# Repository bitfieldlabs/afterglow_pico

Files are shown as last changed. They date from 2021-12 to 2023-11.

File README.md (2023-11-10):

# Afterglow Pico
The afterglow pico is the newest and tiniest addition to the afterglow family.

It operates differently from the other boards as it is hooked directly into the WPC bus. The underlying concept remains the same though. The original lamp matrix is resampled at 4kHz and PWM is used to add a nice afterglow to the LEDs in your pinball machine.

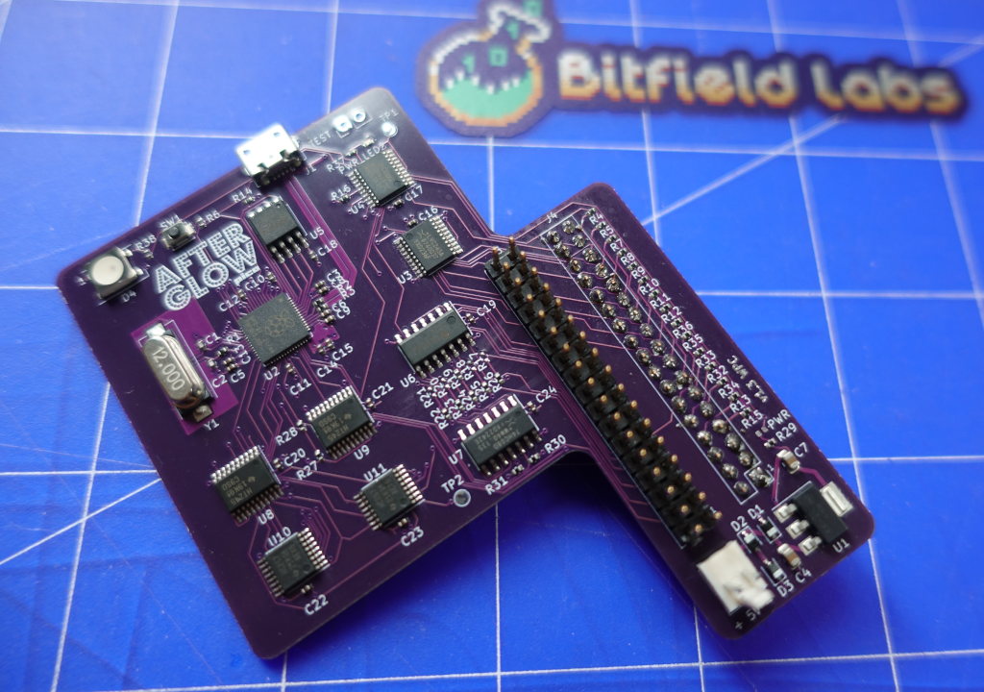
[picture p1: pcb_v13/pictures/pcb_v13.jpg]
afterglow_pico Afterglow Pico


## Disclaimer

| :boom: WARNING  :boom:            |
|:---------------------------|
| **Messing with your pinball machine's data bus is risky!** |
| *The AG pico is an experiment, for stable afterglow please<br>use the standard afterglow boards.* |

Afterglow is distributed in the hope that it will be useful but WITHOUT ANY WARRANTY; without even the implied warranty of
MERCHANTABILITY or FITNESS FOR A PARTICULAR PURPOSE.  See the GNU Lesser General Public License for more details.

## Concept
The concept is quite simple:
* The lamp matrix status is sampled directly from the WPC bus by the Raspberry Pi Pico
* All non lamp related address lines (solenoids etc.) are logically combined (AND) to monitor bus activity
* All non lamp related bus events are directly routed through a multiplexer to the output. Only the lamp events are filtered out. This ensures that original bus events always take precedence over the Pi signals and that no original events are lost.
* The Pi Pico interleaves the upsampled 4kHz PWM lamp matrix events into the bus through the multiplexer

Afterglow Pico Schematic

## Compiling the Raspberry Pi Pico code

The [pi_pico_code folder](https://github.com/bitfieldlabs/afterglow_pico/tree/master/pi_pico_code) contains a [platformio](https://platformio.org/) project which can be compiled using [Visual Studio Code](https://code.visualstudio.com/). It requires the [wizio-pico](https://github.com/Wiz-IO/wizio-pico) platform extension.

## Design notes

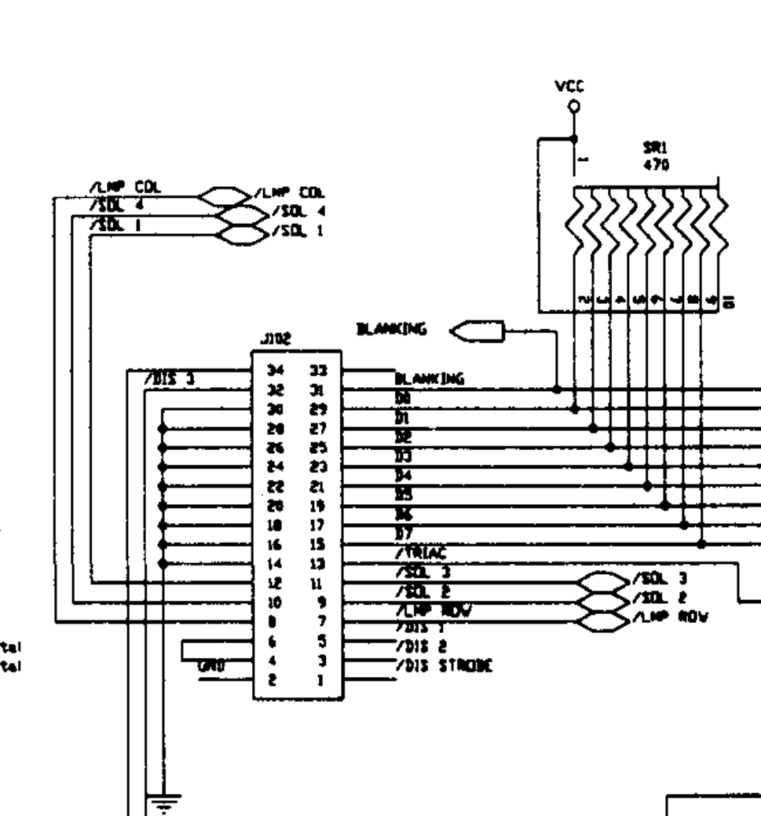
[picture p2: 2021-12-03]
docs/wpc95_bus.png

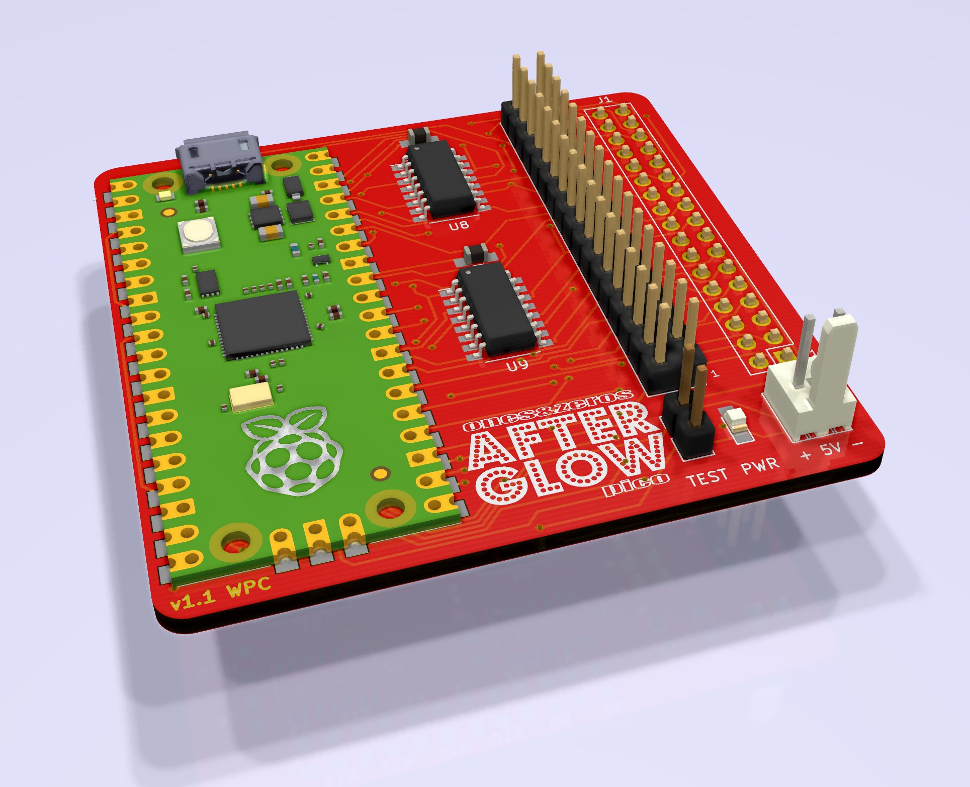
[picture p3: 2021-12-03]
docs/pcb_v11_render.jpg

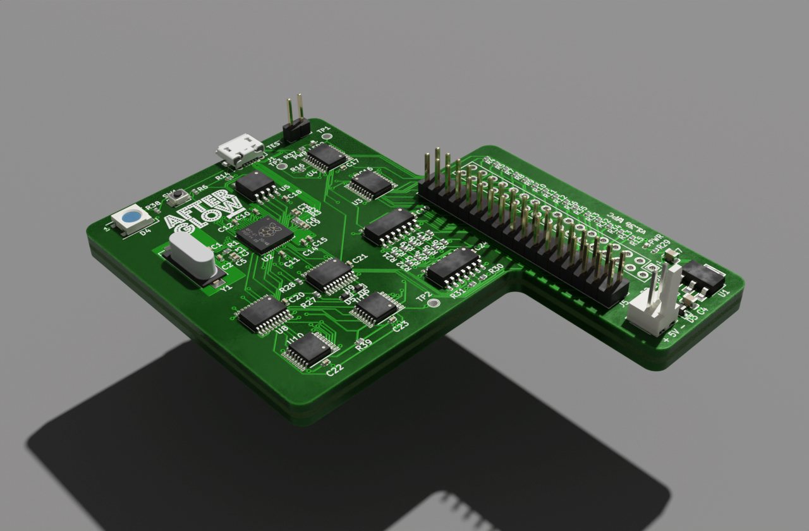
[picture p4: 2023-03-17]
pcb_v13/render/pcb_v13_b.jpg

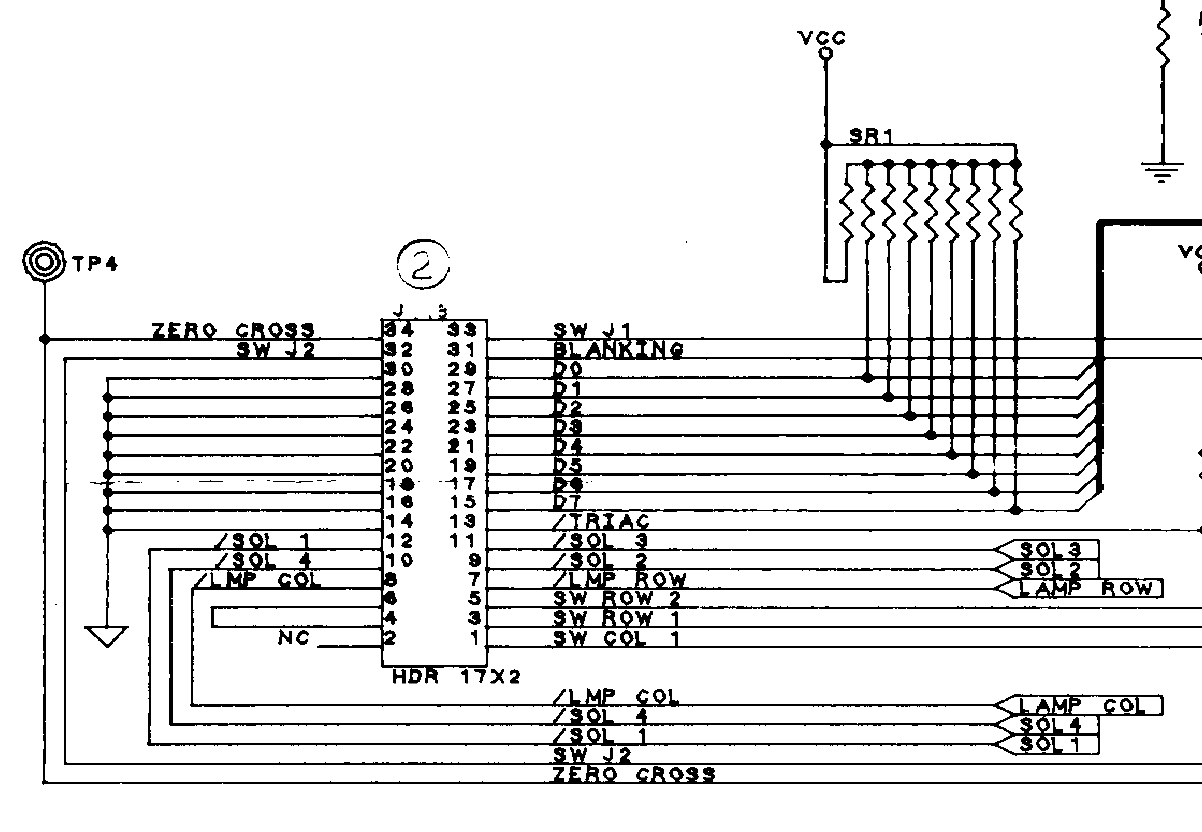
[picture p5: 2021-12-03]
docs/wpc_bus.png

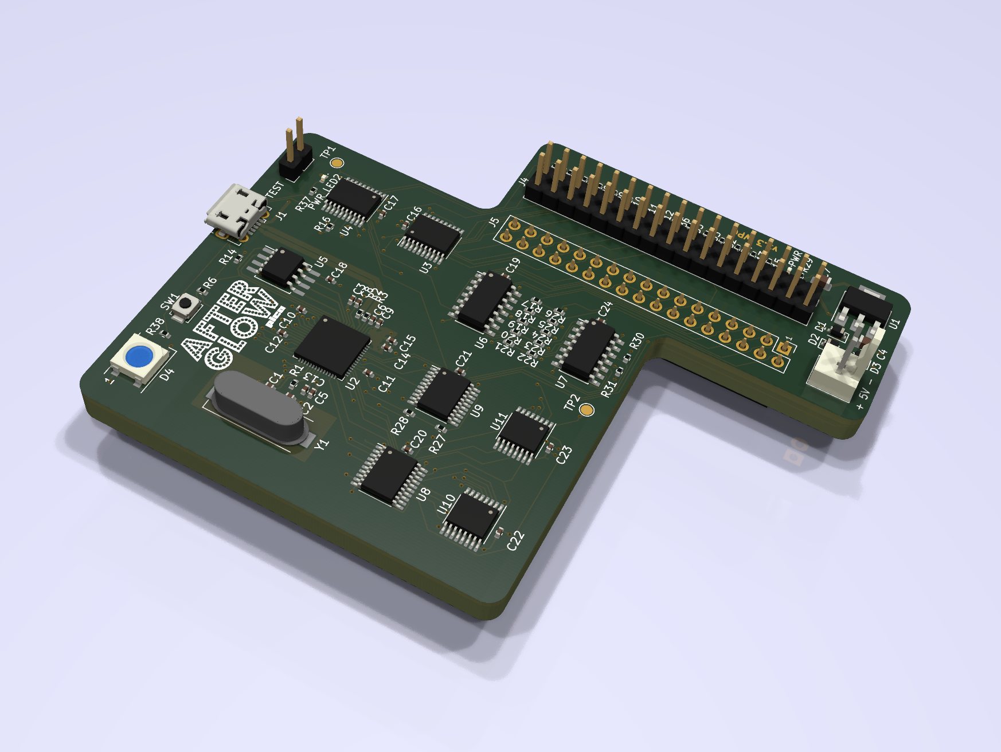
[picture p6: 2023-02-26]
pcb_v13/render/pcb_v13.jpg

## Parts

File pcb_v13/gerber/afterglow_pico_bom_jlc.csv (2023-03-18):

Comment | Designator | Footprint | LCSC Part #
27p | C1,C2 | C_0402_1005Metric | C107002
100n | C3,C5,C8,C10,C11,C12,C13,C14,C15,C18 | C_0402_1005Metric | C131394
10u | C4,C7 | C_0805_2012Metric | C89189
1u | C6,C9 | C_0402_1005Metric | C326568
100nF | C16,C17,C19,C20,C21,C22,C23,C24 | C_0402_1005Metric | C131394
BAT60A | D1,D2,D3 | D_SOD-323 | C520634
WS2812B | D4 | LED_WS2812B_PLCC4_5.0x5.0mm_P3.2mm | C2761795
1N4148 | D5,D6 | D_SOD-523 | C2961218
USB_B_Micro | J1 | USB_Micro-B_Molex-105017-0001 | C505111
Conn_02x17_Odd_Even | J5 | PinHeader_2x17_P2.54mm_Vertical | C2894978
LED | PWR1 | LED_0402_1005Metric | C434449
LED | PWR_LED2 | LED_0402_1005Metric | C130719
1k | R1,R6,R29,R37 | R_0402_1005Metric | C106235
27 | R2,R3 | R_0402_1005Metric | C137890
470 | R4,R5,R7,R8,R9,R10,R11,R12 | R_0402_1005Metric | C114877
1.5k | R13 | R_0402_1005Metric | C114759
10k | R14 | R_0402_1005Metric | C60489
6.8k | R15 | R_0402_1005Metric | C137847
4.7k | R16,R22,R23,R24,R25,R26,R27,R28,R30,R31,R32,R33,R34,R35,R36,R39 | R_0402_1005Metric | C105871
0 | R19 | R_0402_1005Metric | C138289
220 | R38 | R_0402_1005Metric | C227335
SW_Push | SW1 | SW_SPST_B3U-1000P | C231329
Conn_01x02 | TEST_MODE1 | PinHeader_1x02_P2.54mm_Vertical | C124375
NCP1117-3.3_SOT223 | U1 | SOT-223-3_TabPin2 | C26537
RP2040 | U2 | RP2040-QFN-56 | C2040
SN74LVC245AN | U3,U4 | TSSOP-20_4.4x6.5mm_P0.65mm | C6082
W25Q32JVSS | U5 | SOIC-8_5.23x5.23mm_P1.27mm | C82344
74HC21 | U6 | SOIC-14_3.9x8.7mm_P1.27mm | C75398
7408 | U7 | SOIC-14_3.9x8.7mm_P1.27mm | C5593
74HCT245 | U8,U9 | TSSOP-20_4.4x6.5mm_P0.65mm | C6779
74HC257 | U10,U11 | TSSOP-16_4.4x5mm_P0.65mm | C7646
ABLS-12.000MHZ-B4-T | Y1 | Crystal_SMD_HC49-US | C390753

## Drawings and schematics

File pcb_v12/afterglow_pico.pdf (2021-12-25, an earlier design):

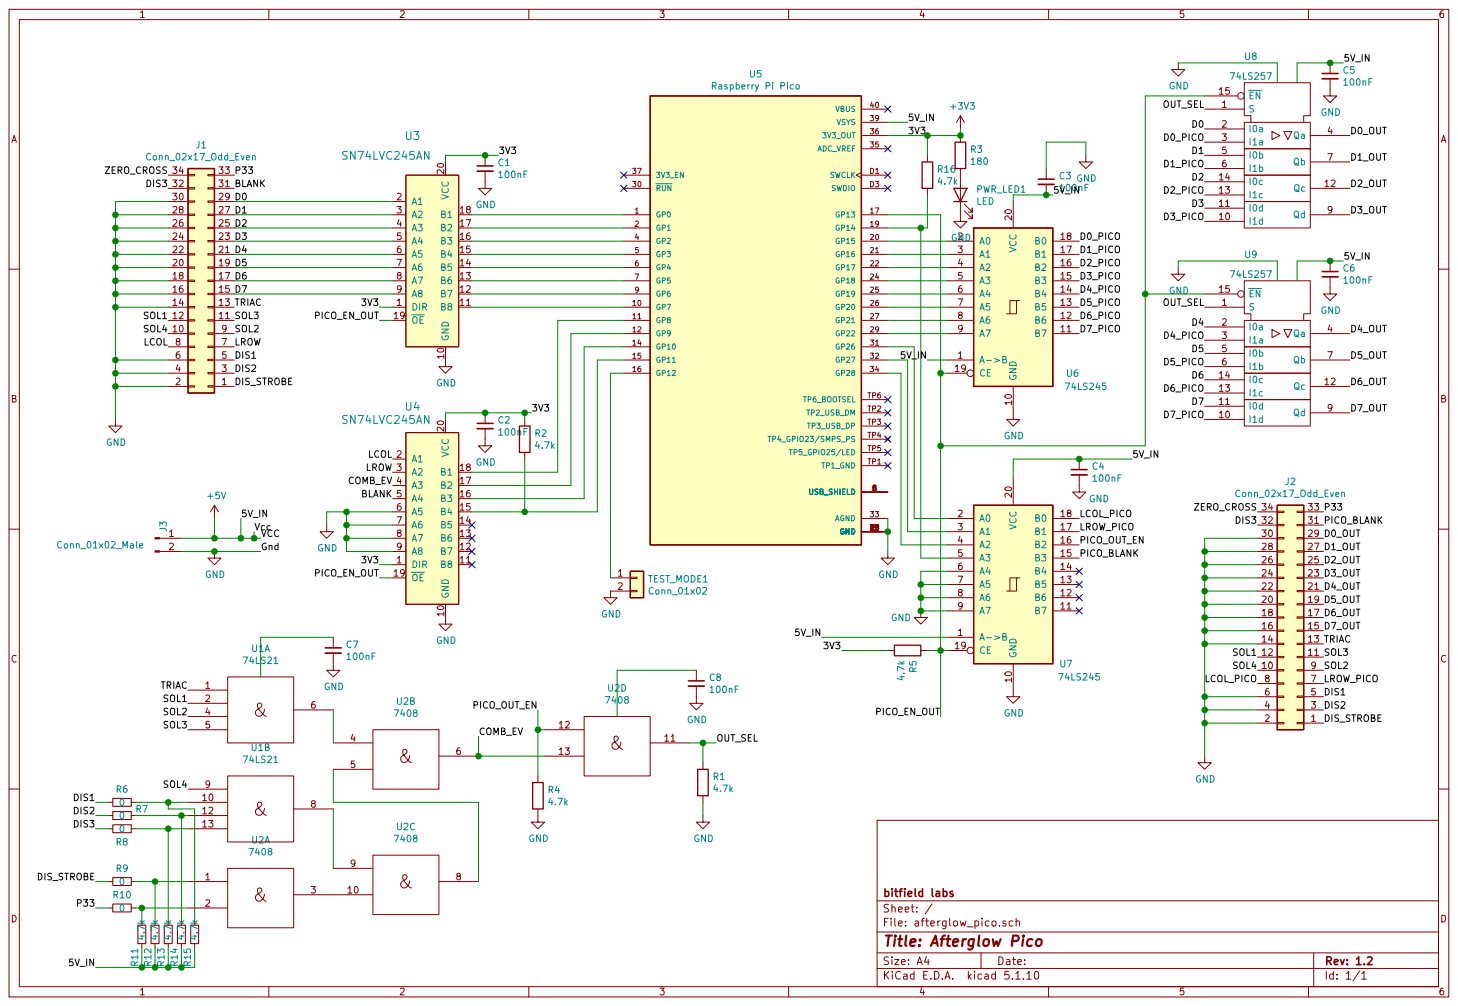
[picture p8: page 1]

26 | 25
24 | 23
22 | 21
20 | 19
18 | 17
16 | 15

File: afterglow_pico.sch Sheet: / bitfield labs

Id: 1/1 Title: Afterglow Pico

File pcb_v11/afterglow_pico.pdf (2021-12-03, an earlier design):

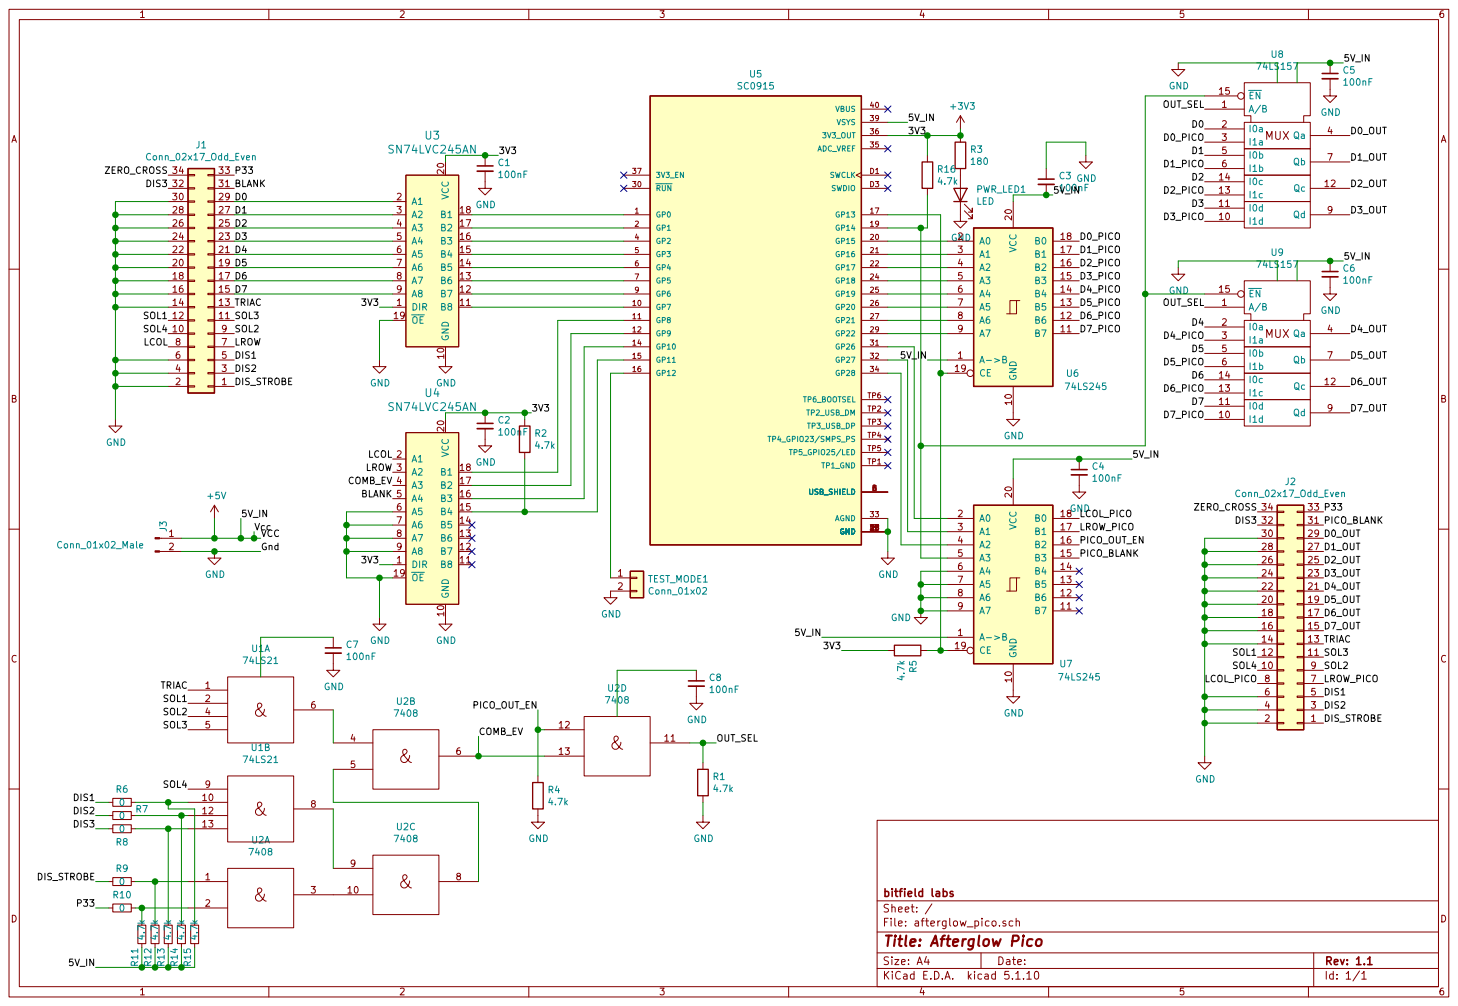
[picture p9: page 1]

28 | 27
26 | 25
24 | 23
22 | 21 D4
20 | 19
18 | 17
16 | 15

Id: 1/1 Title: Afterglow Pico

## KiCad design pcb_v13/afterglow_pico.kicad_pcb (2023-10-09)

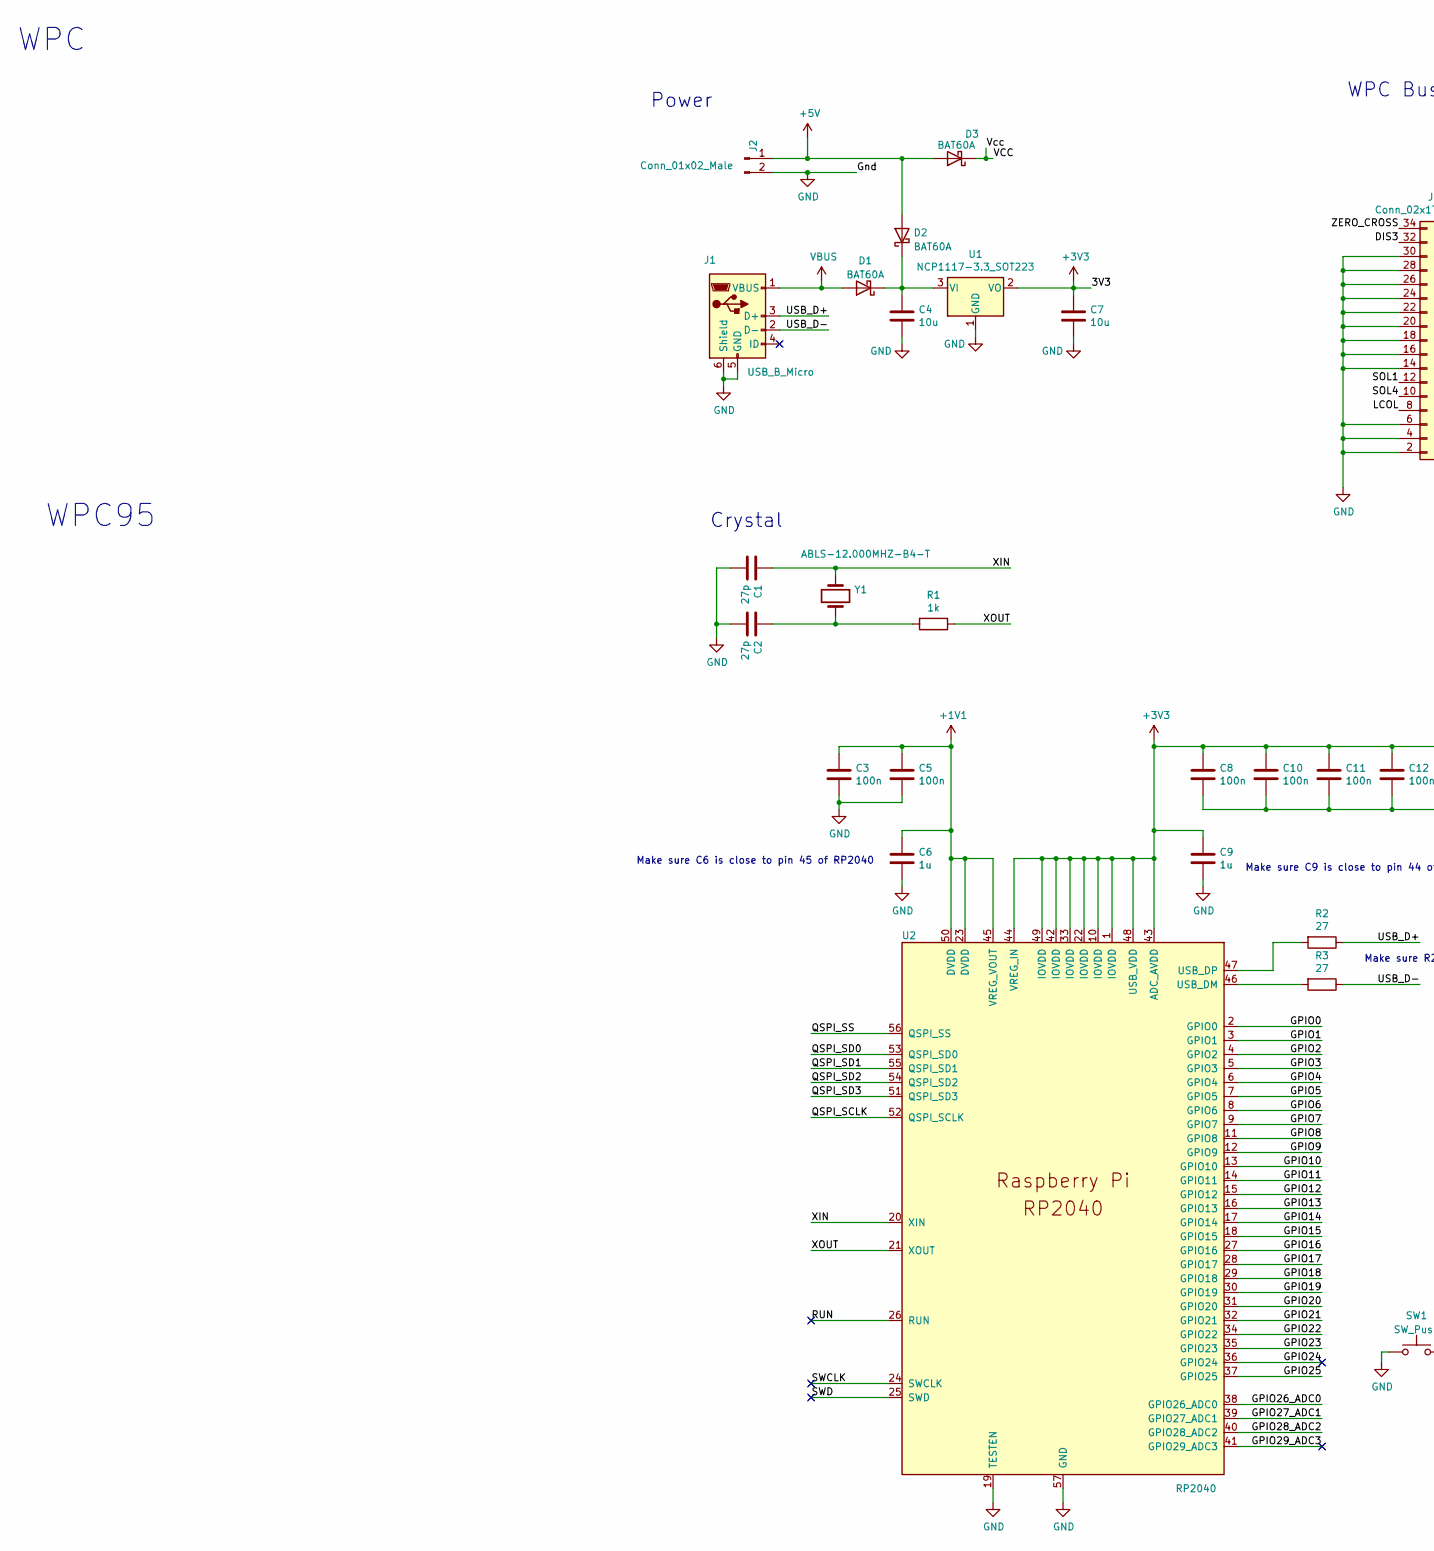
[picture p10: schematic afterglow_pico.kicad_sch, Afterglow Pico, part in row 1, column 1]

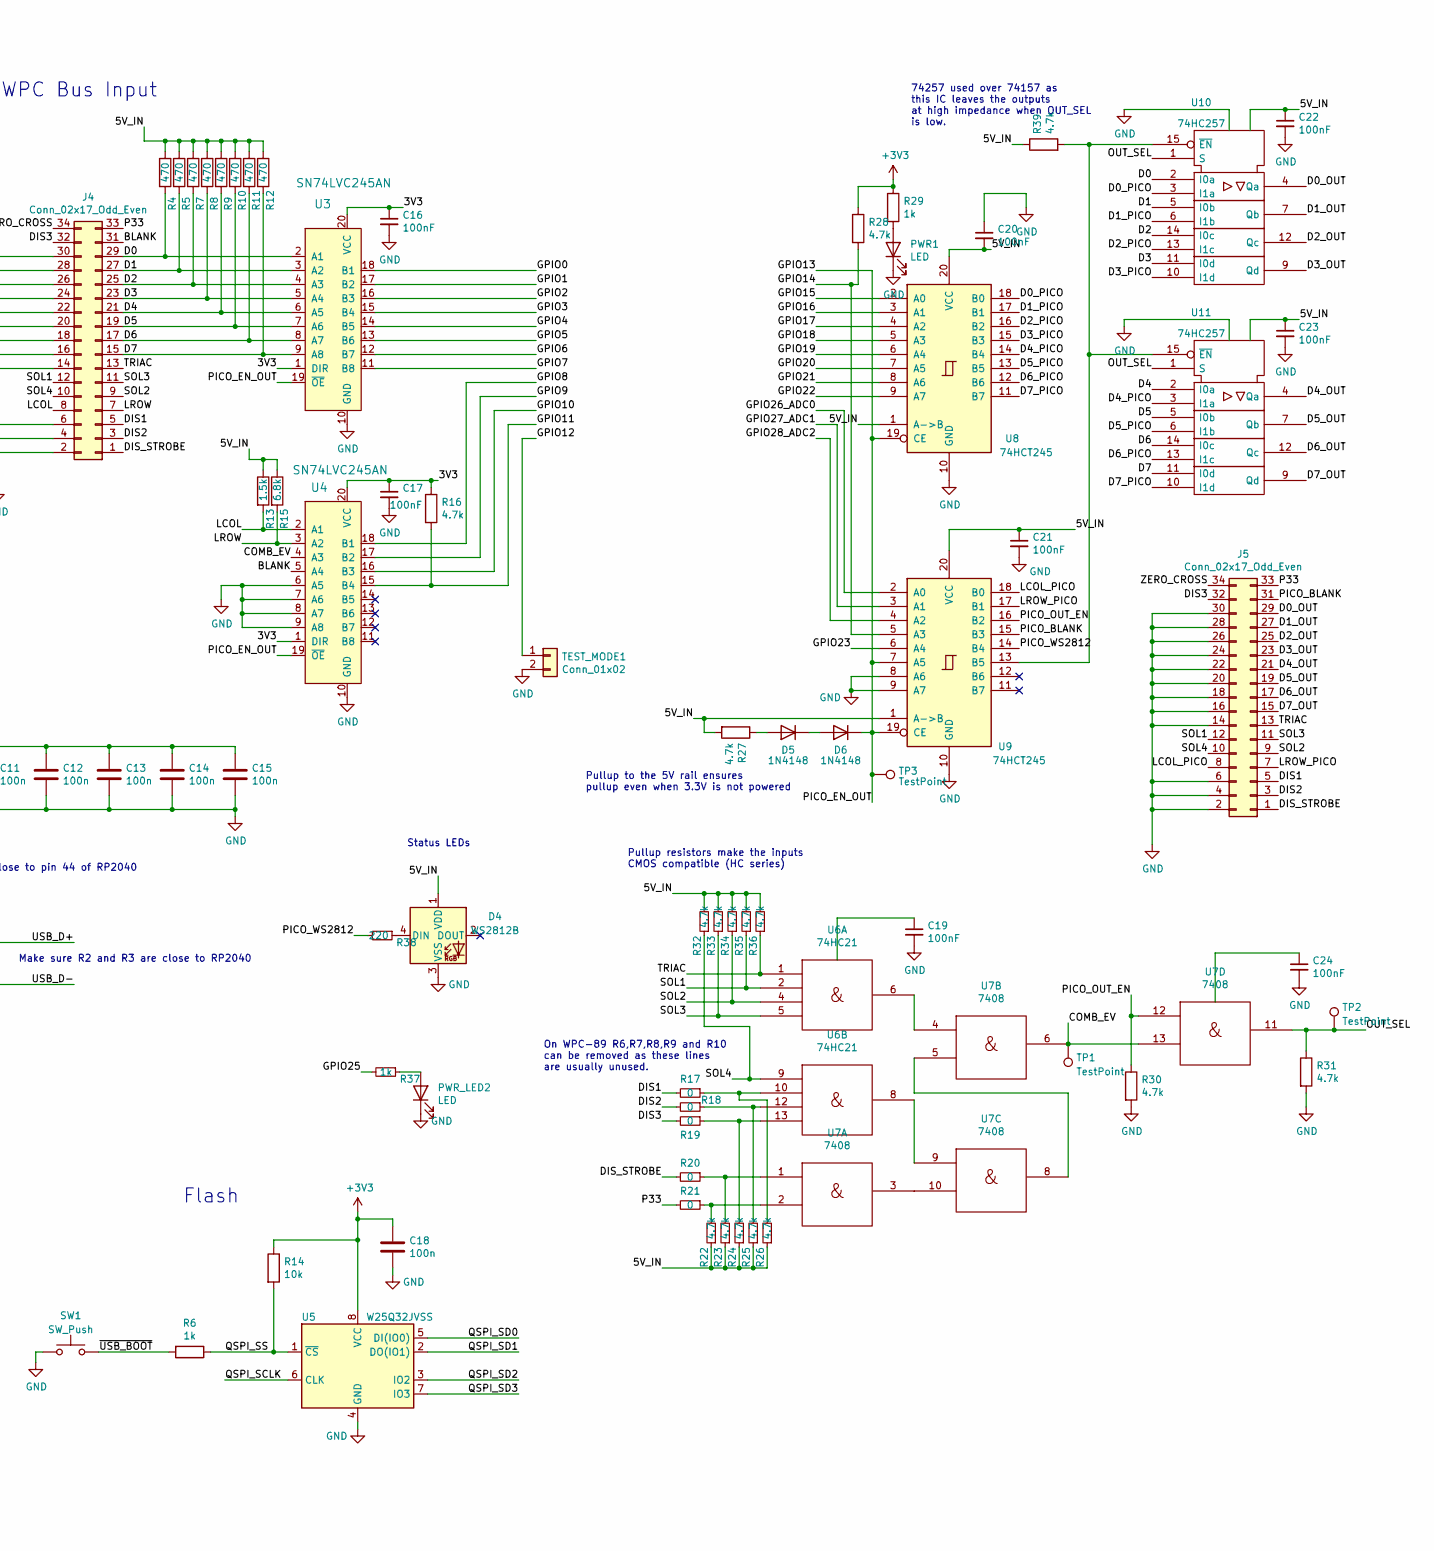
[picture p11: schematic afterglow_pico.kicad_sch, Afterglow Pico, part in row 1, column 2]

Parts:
C1, C2: 27p; C_0402_1005Metric; JLCPCB C107002
C3, C5, C8, C10, C11, C12, C13, C14, C15, C18: 100n; C_0402_1005Metric; JLCPCB C131394
C4, C7: 10u; C_0805_2012Metric; JLCPCB C89189
C6, C9: 1u; C_0402_1005Metric; JLCPCB C326568
C16, C17, C19, C20, C21, C22, C23, C24: 100nF; C_0402_1005Metric; JLCPCB C131394
D1, D2, D3: BAT60A; D_SOD-323; JLCPCB C520634
D4: WS2812B; LED_WS2812B_PLCC4_5.0x5.0mm_P3.2mm; JLCPCB C2761795
D5, D6: 1N4148; D_SOD-523; JLCPCB C2961218
J1: USB_B_Micro; USB_Micro-B_Molex-105017-0001; JLCPCB C505111
J2: Conn_01x02_Male; Molex_KK-254_AE-6410-02A_1x02_P2.54mm_Vertical
J4: Conn_02x17_Odd_Even; PinHeader_2x17_P2.54mm_Vertical
J5: Conn_02x17_Odd_Even; PinHeader_2x17_P2.54mm_Vertical; JLCPCB C2894978
PWR1: LED; LED_0402_1005Metric; JLCPCB C434449
PWR_LED2: LED; LED_0402_1005Metric; JLCPCB C130719
R1, R6, R29, R37: 1k; R_0402_1005Metric; JLCPCB C106235
R2, R3: 27; R_0402_1005Metric; JLCPCB C137890
R4, R5, R7, R8, R9, R10, R11, R12: 470; R_0402_1005Metric; JLCPCB C114877
R13: 1.5k; R_0402_1005Metric; JLCPCB C114759
R14: 10k; R_0402_1005Metric; JLCPCB C60489
R15: 6.8k; R_0402_1005Metric; JLCPCB C137847
R16, R22, R23, R24, R25, R26, R27, R28, R30, R31, R32, R33, R34, R35, R36, R39: 4.7k; R_0402_1005Metric; JLCPCB C105871
R17, R18, R20, R21: 0; R_0402_1005Metric
R19: 0; R_0402_1005Metric; JLCPCB C138289
R38: 220; R_0402_1005Metric; JLCPCB C227335
SW1: SW_Push; SW_SPST_B3U-1000P; JLCPCB C231329
TEST_MODE1: Conn_01x02; PinHeader_1x02_P2.54mm_Vertical; JLCPCB C124375
TP1, TP2, TP3: TestPoint; TestPoint_Pad_D1.5mm
U1: NCP1117-3.3_SOT223; SOT-223-3_TabPin2; JLCPCB C26537
U2: RP2040; RP2040-QFN-56; JLCPCB C2040
U3, U4: SN74LVC245AN; TSSOP-20_4.4x6.5mm_P0.65mm; MPN SN74LVC245AN; Digi-Key_PN 296-8503-5-ND
U5: W25Q32JVSS; SOIC-8_5.23x5.23mm_P1.27mm; JLCPCB C82344
U6: 74HC21; SOIC-14_3.9x8.7mm_P1.27mm; JLCPCB C75398
U7: 7408; SOIC-14_3.9x8.7mm_P1.27mm; JLCPCB C5593
U8, U9: 74HCT245; TSSOP-20_4.4x6.5mm_P0.65mm; JLCPCB C6779
U10, U11: 74HC257; TSSOP-16_4.4x5mm_P0.65mm; JLCPCB C7646
Y1: ABLS-12.000MHZ-B4-T; Crystal_SMD_HC49-US; JLCPCB C390753

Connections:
+1V1: C3.1, C5.1, C6.1, U2.23 (DVDD), U2.45 (VREG_VOUT), U2.50 (DVDD)
+3V3: C7.1, C8.1, C9.1, C10.1, C11.1, C12.1, C13.1, C14.1, C15.1, C16.1, C17.1, C18.1, R14.1, R16.1, R28.1, R29.1, U1.2 (VO), U2.1 (IOVDD), U2.10 (IOVDD), U2.22 (IOVDD), U2.33 (IOVDD), U2.42 (IOVDD), U2.43 (ADC_AVDD), U2.44 (VREG_IN), U2.48 (USB_VDD), U2.49 (IOVDD), U3.1 (DIR), U3.20 (VCC), U4.1 (DIR), U4.20 (VCC), U5.8 (VCC)
+5V: D2.2 (A), D3.2 (A), J2.1; also elsewhere on the board
/BLANK: J4.31, U4.5 (A4)
/COMB_EV: TP1.1, U4.4 (A3), U7.6, U7.13
/D0: J4.29, R4.2, U3.2 (A1), U10.2 (I0a)
/D0_OUT: J5.29, U10.4 (Qa)
/D0_PICO: U8.18 (B0), U10.3 (I1a)
/D1: J4.27, R5.2, U3.3 (A2), U10.5 (I0b)
/D1_OUT: J5.27, U10.7 (Qb)
/D1_PICO: U8.17 (B1), U10.6 (I1b)
/D2: J4.25, R7.2, U3.4 (A3), U10.14 (I0c)
/D2_OUT: J5.25, U10.12 (Qc)
/D2_PICO: U8.16 (B2), U10.13 (I1c)
/D3: J4.23, R8.2, U3.5 (A4), U10.11 (I0d)
/D3_OUT: J5.23, U10.9 (Qd)
/D3_PICO: U8.15 (B3), U10.10 (I1d)
/D4: J4.21, R9.2, U3.6 (A5), U11.2 (I0a)
/D4_OUT: J5.21, U11.4 (Qa)
/D4_PICO: U8.14 (B4), U11.3 (I1a)
/D5: J4.19, R10.2, U3.7 (A6), U11.5 (I0b)
/D5_OUT: J5.19, U11.7 (Qb)
/D5_PICO: U8.13 (B5), U11.6 (I1b)
/D6: J4.17, R11.2, U3.8 (A7), U11.14 (I0c)
/D6_OUT: J5.17, U11.12 (Qc)
/D6_PICO: U8.12 (B6), U11.13 (I1c)
/D7: J4.15, R12.2, U3.9 (A8), U11.11 (I0d)
/D7_OUT: J5.15, U11.9 (Qd)
/D7_PICO: U8.11 (B7), U11.10 (I1d)
/DIS1: J4.5, J5.5, R17.2
/DIS2: J4.3, J5.3, R18.2
/DIS3: J4.32, J5.32, R19.2
/DIS_STROBE: J4.1, J5.1, R20.2
/GPIO0: U2.2 (GPIO0), U3.18 (B1)
/GPIO1: U2.3 (GPIO1), U3.17 (B2)
/GPIO2: U2.4 (GPIO2), U3.16 (B3)
/GPIO3: U2.5 (GPIO3), U3.15 (B4)
/GPIO4: U2.6 (GPIO4), U3.14 (B5)
/GPIO5: U2.7 (GPIO5), U3.13 (B6)
/GPIO6: U2.8 (GPIO6), U3.12 (B7)
/GPIO7: U2.9 (GPIO7), U3.11 (B8)
/GPIO8: U2.11 (GPIO8), U4.18 (B1)
/GPIO9: U2.12 (GPIO9), U4.17 (B2)
/GPIO10: U2.13 (GPIO10), U4.16 (B3)
/GPIO11: R16.2, U2.14 (GPIO11), U4.15 (B4)
/GPIO12: TEST_MODE1.1, U2.15 (GPIO12); also elsewhere on the board
/GPIO13: D6.1 (K), TP3.1, U2.16 (GPIO13), U3.19 (~OE), U4.19 (~OE), U8.19 (CE), U9.7 (A5), U9.19 (CE)
/GPIO14: R28.2, U2.17 (GPIO14), U9.5 (A3)
/GPIO15: U2.18 (GPIO15), U8.2 (A0)
/GPIO16: U2.27 (GPIO16), U8.3 (A1)
/GPIO17: U2.28 (GPIO17), U8.4 (A2)
/GPIO18: U2.29 (GPIO18), U8.5 (A3)
/GPIO19: U2.30 (GPIO19), U8.6 (A4)
/GPIO20: U2.31 (GPIO20), U8.7 (A5)
/GPIO21: U2.32 (GPIO21), U8.8 (A6)
/GPIO22: U2.34 (GPIO22), U8.9 (A7)
/GPIO23: U2.35 (GPIO23), U9.6 (A4)
/GPIO24: U2.36 (GPIO24)
/GPIO25: R37.2, U2.37 (GPIO25)
/GPIO26_ADC0: U2.38 (GPIO26_ADC0), U9.2 (A0)
/GPIO27_ADC1: U2.39 (GPIO27_ADC1), U9.3 (A1)
/GPIO28_ADC2: U2.40 (GPIO28_ADC2), U9.4 (A2)
/GPIO29_ADC3: U2.41 (GPIO29_ADC3)
/LCOL: J4.8, R13.2, U4.2 (A1)
/LCOL_PICO: J5.8, U9.18 (B0)
/LROW: J4.7, R15.2, U4.3 (A2)
/LROW_PICO: J5.7, U9.17 (B1)
/OUT_SEL: R31.1, TP2.1, U7.11, U10.1 (S), U11.1 (S)
/P33: J4.33, J5.33, R21.2
/PICO_BLANK: J5.31, U9.15 (B3)
/PICO_OUT_EN: R30.1, U7.12, U9.16 (B2)
/PICO_WS2812: R38.2, U9.14 (B4)
/QSPI_SCLK: U2.52 (QSPI_SCLK), U5.6 (CLK)
/QSPI_SD0: U2.53 (QSPI_SD0), U5.5 (DI(IO0))
/QSPI_SD1: U2.55 (QSPI_SD1), U5.2 (DO(IO1))
/QSPI_SD2: U2.54 (QSPI_SD2), U5.3 (IO2)
/QSPI_SD3: U2.51 (QSPI_SD3), U5.7 (IO3)
/QSPI_SS: R6.1, R14.2, U2.56 (QSPI_SS), U5.1 (~CS)
/RUN: U2.26 (RUN)
/SOL1: J4.12, J5.12, R35.1, U6.2
/SOL2: J4.9, J5.9, R34.1, U6.4
/SOL3: J4.11, J5.11, R33.1, U6.5
/SOL4: J4.10, J5.10, R32.1, U6.9
/SWCLK: U2.24 (SWCLK)
/SWD: U2.25 (SWD)
/TRIAC: J4.13, J5.13, R36.1, U6.1
/USB_D+: J1.3 (D+), R2.1
/USB_D-: J1.2 (D-), R3.1
/XIN: C1.1, U2.20 (XIN), Y1.1
/XOUT: R1.1, U2.21 (XOUT)
/ZERO_CROSS: J4.34, J5.34
/~USB_BOOT: R6.2, SW1.2
GND: C1.2, C2.2, C3.2, C4.2, C5.2, C6.2, C7.2, C8.2, C9.2, C10.2, C11.2, C12.2, C13.2, C14.2, C15.2, C16.2, C17.2, C18.2, C19.2, C20.1, C21.2, C22.2, C23.2, C24.2, D4.3 (VSS), J1.5 (GND), J1.6 (Shield), J2.2, J4.2, J4.4, J4.6, J4.14, J4.16, J4.18, J4.20, J4.22, J4.24, J4.26, J4.28, J4.30, J5.2, J5.4, J5.6, J5.14, J5.16, J5.18, J5.20, J5.22, J5.24, J5.26, J5.28, J5.30, PWR1.1 (K), PWR_LED2.1 (K), R30.2, R31.2, SW1.1, TEST_MODE1.2, U1.1 (GND), U2.19 (TESTEN), U2.57 (GND), U3.10 (GND), U4.6 (A5), U4.7 (A6), U4.8 (A7), U4.9 (A8), U4.10 (GND), U5.4 (GND), U6.7 (Gnd), U7.7 (Gnd), U8.10 (GND), U9.8 (A6), U9.9 (A7), U9.10 (GND), U10.8 (GND), U11.8 (GND); also elsewhere on the board
unnamed: C2.1, R1.2, Y1.2
unnamed: C4.1, D1.1 (K), D2.1 (K), U1.3 (VI)
unnamed: D4.4 (DIN), R38.1
unnamed: D5.2 (A), R27.1
unnamed: D5.1 (K), D6.2 (A)
unnamed 98: PWR1.2 (A), R29.2; also elsewhere on the board
unnamed: PWR_LED2.2 (A), R37.1
unnamed: R17.1, R26.2, U6.10
unnamed: R18.1, R25.2, U6.12
unnamed: R19.1, R24.2, U6.13
unnamed: R20.1, R23.2, U7.1
unnamed: R21.1, R22.2, U7.2
unnamed: R3.2, U2.46 (USB_DM)
unnamed: R2.2, U2.47 (USB_DP)
unnamed: U6.6, U7.4
unnamed: U6.8, U7.9
unnamed: U7.5, U7.8
unnamed: U7.3, U7.10
unnamed: R39.2, U9.13 (B5), U10.15 (~EN), U11.15 (~EN)
VBUS: D1.2 (A), J1.1 (VBUS)

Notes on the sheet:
WPC
Pullup to the 5V rail ensures pullup even when 3.3V is not powered
Status LEDs
Pullup resistors make the inputs CMOS compatible (HC series)
Make sure C9 is close to pin 44 of RP2040
Power
Crystal
74257 used over 74157 as this IC leaves the outputs at high impedance when OUT_SEL is low.
On WPC-89 R6,R7,R8,R9 and R10 can be removed as these lines are usually unused.
WPC Bus Input
WPC95
Make sure R2 and R3 are close to RP2040
Flash
Make sure C6 is close to pin 45 of RP2040

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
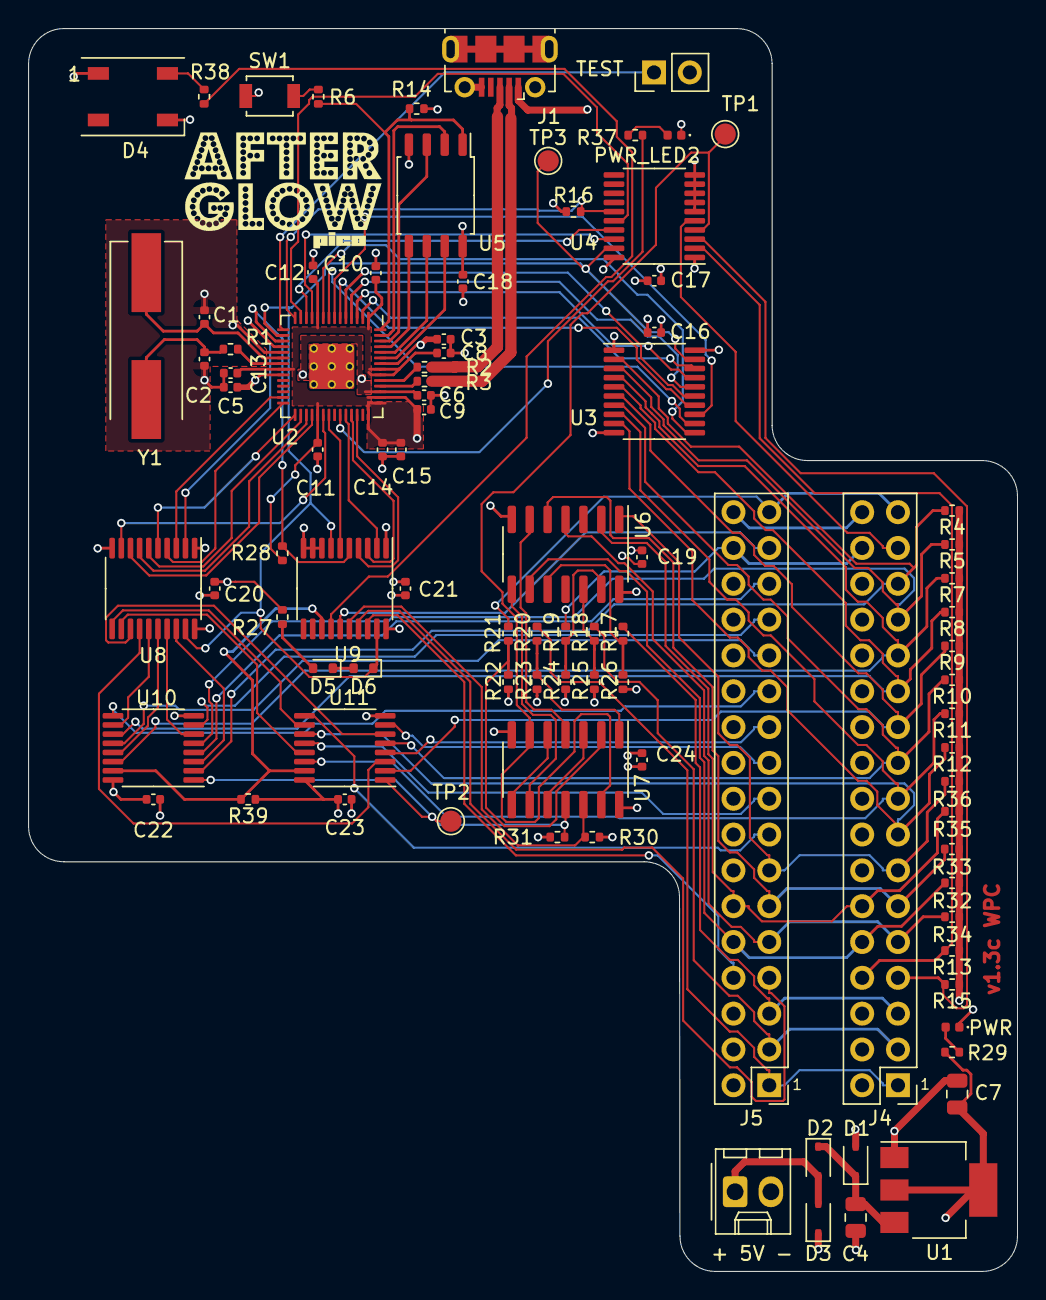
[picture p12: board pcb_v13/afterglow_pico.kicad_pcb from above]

Board: 4 copper layers, 70.1 x 88.1 mm, 93 parts (0 on the bottom side), 109 nets.

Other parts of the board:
+ 5V -: Conn_01x02_Male; Molex_KK-254_AE-6410-02A_1x02_P2.54mm_Vertical
LOGO: LOGO; ag_pico_logo_2
PWR: LED; LED_0402_1005Metric
TEST: Conn_01x02; PinHeader_1x02_P2.54mm_Vertical

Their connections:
+5V: + 5V -.1; also elsewhere on the board
/GPIO12: TEST.1; also elsewhere on the board
GND: + 5V -.2, PWR.1 (K), TEST.2; also elsewhere on the board
unnamed 98: PWR.2 (A); also elsewhere on the board

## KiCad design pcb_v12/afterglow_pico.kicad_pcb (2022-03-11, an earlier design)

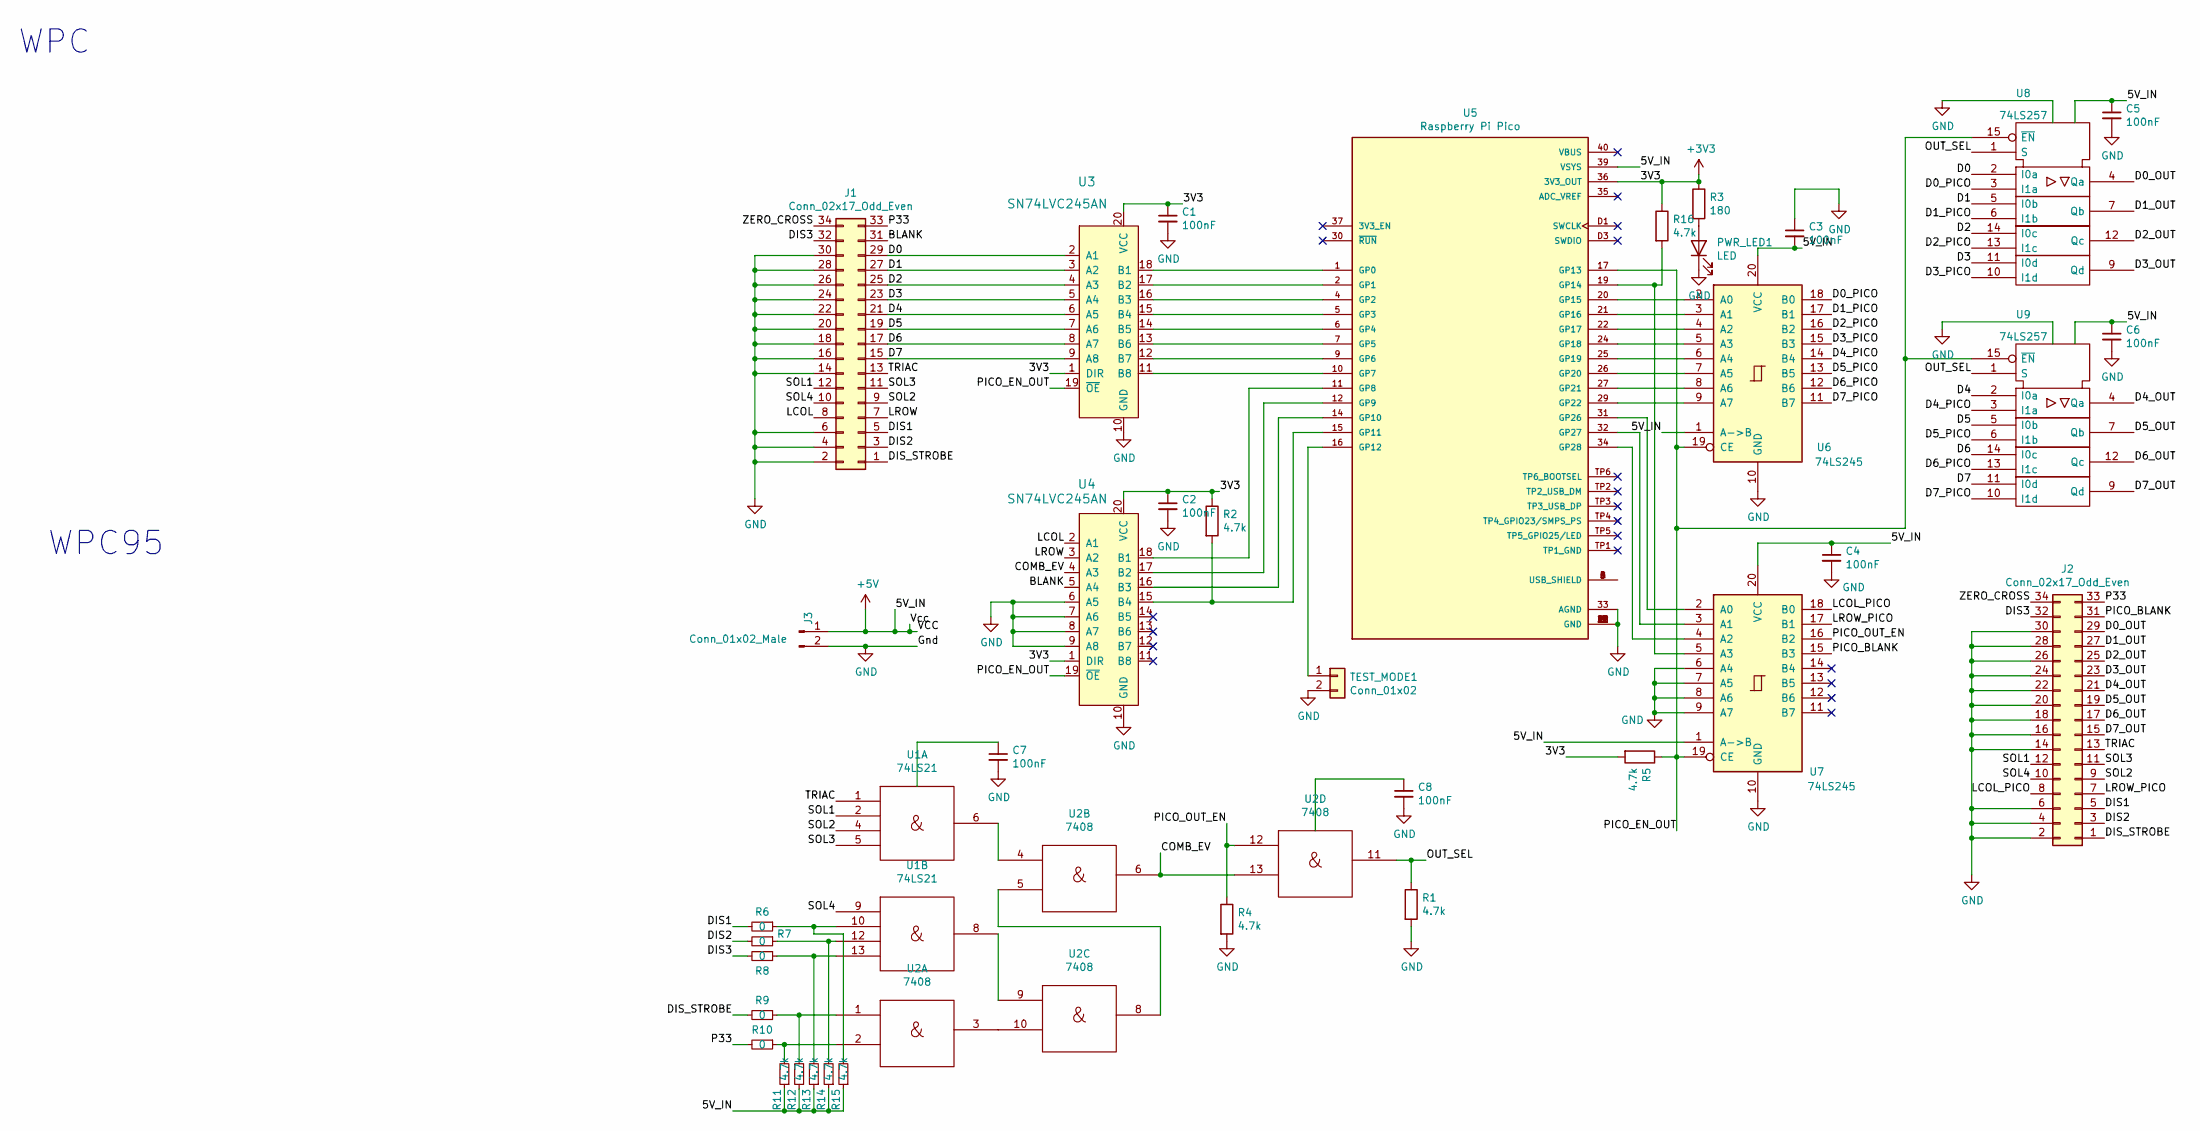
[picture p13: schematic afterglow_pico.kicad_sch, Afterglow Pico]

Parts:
C1, C2, C3, C4, C5, C6, C7, C8: 100nF; C_0805_HandSoldering; JLCPCB C396718
J1, J2: Conn_02x17_Odd_Even; Pin_Header_Straight_2x17_Pitch2.54mm
J3: Conn_01x02_Male; Molex_KK-6410-02_02x2.54mm_Straight
PWR_LED1: LED; LED_0805_HandSoldering; JLCPCB C434432
R1, R2, R4, R5, R11, R12, R13, R14, R15, R16: 4.7k; R_0805_HandSoldering; JLCPCB C17673
R3: 180; R_0805_HandSoldering; JLCPCB C25270
R6, R7, R8, R9, R10: 0; R_0805_HandSoldering; JLCPCB C17477
TEST_MODE1: Conn_01x02; Pin_Header_Straight_1x02_Pitch2.54mm
U1: 74LS21; SOIC-14_3.9x8.7mm_Pitch1.27mm; JLCPCB C2862597
U2: 7408; SOIC-14_3.9x8.7mm_Pitch1.27mm; JLCPCB C6802
U3, U4: SN74LVC245AN; SOIC-20W_7.5x12.8mm_Pitch1.27mm; MPN SN74LVC245AN; Digi-Key_PN 296-8503-5-ND
U5: Raspberry Pi Pico; MODULE_SC0915; PARTREV 1.6
U6, U7: 74LS245; SOIC-20W_7.5x12.8mm_Pitch1.27mm; JLCPCB C129580
U8, U9: 74LS257; SOP-16_4.4x10.4mm_Pitch1.27mm; JLCPCB C7754

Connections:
+3V3: C1.1, C2.1, R2.1, R3.1, R5.2, R16.1, U3.1 (DIR), U3.20 (VCC), U4.1 (DIR), U4.20 (VCC), U5.36 (3V3_OUT)
/BLANK: J1.31, U4.5 (A4)
/COMB_EV: U2.6, U2.13, U4.4 (A3)
/D0: J1.29, U3.2 (A1), U8.2 (I0a)
/D0_OUT: J2.29, U8.4 (Qa)
/D0_PICO: U6.18 (B0), U8.3 (I1a)
/D1: J1.27, U3.3 (A2), U8.5 (I0b)
/D1_OUT: J2.27, U8.7 (Qb)
/D1_PICO: U6.17 (B1), U8.6 (I1b)
/D2: J1.25, U3.4 (A3), U8.14 (I0c)
/D2_OUT: J2.25, U8.12 (Qc)
/D2_PICO: U6.16 (B2), U8.13 (I1c)
/D3: J1.23, U3.5 (A4), U8.11 (I0d)
/D3_OUT: J2.23, U8.9 (Qd)
/D3_PICO: U6.15 (B3), U8.10 (I1d)
/D4: J1.21, U3.6 (A5), U9.2 (I0a)
/D4_OUT: J2.21, U9.4 (Qa)
/D4_PICO: U6.14 (B4), U9.3 (I1a)
/D5: J1.19, U3.7 (A6), U9.5 (I0b)
/D5_OUT: J2.19, U9.7 (Qb)
/D5_PICO: U6.13 (B5), U9.6 (I1b)
/D6: J1.17, U3.8 (A7), U9.14 (I0c)
/D6_OUT: J2.17, U9.12 (Qc)
/D6_PICO: U6.12 (B6), U9.13 (I1c)
/D7: J1.15, U3.9 (A8), U9.11 (I0d)
/D7_OUT: J2.15, U9.9 (Qd)
/D7_PICO: U6.11 (B7), U9.10 (I1d)
/DIS1: J1.5, J2.5, R6.2
/DIS2: J1.3, J2.3, R7.2
/DIS3: J1.32, J2.32, R8.2
/DIS_STROBE: J1.1, J2.1, R9.2
/LCOL: J1.8, U4.2 (A1)
/LCOL_PICO: J2.8, U7.18 (B0)
/LROW: J1.7, U4.3 (A2)
/LROW_PICO: J2.7, U7.17 (B1)
/OUT_SEL: R1.1, U2.11, U8.1 (S), U9.1 (S)
/P33: J1.33, J2.33, R10.2
/PICO_BLANK: J2.31, U7.15 (B3)
/PICO_EN_OUT: R5.1, U3.19 (~OE), U4.19 (~OE), U5.17 (GP13), U6.19 (CE), U7.19 (CE), U8.15 (~EN), U9.15 (~EN)
/PICO_OUT_EN: R4.1, U2.12, U7.16 (B2)
/SOL1: J1.12, J2.12, U1.2
/SOL2: J1.9, J2.9, U1.4
/SOL3: J1.11, J2.11, U1.5
/SOL4: J1.10, J2.10, U1.9
/TRIAC: J1.13, J2.13, U1.1
/ZERO_CROSS: J1.34, J2.34
GND: C1.2, C2.2, C3.1, C4.2, C5.2, C6.2, C7.2, C8.2, J1.2, J1.4, J1.6, J1.14, J1.16, J1.18, J1.20, J1.22, J1.24, J1.26, J1.28, J1.30, J2.2, J2.4, J2.6, J2.14, J2.16, J2.18, J2.20, J2.22, J2.24, J2.26, J2.28, J2.30, J3.2, PWR_LED1.1 (K), R1.2, R4.2, TEST_MODE1.2, U1.7 (Gnd), U2.7 (Gnd), U3.10 (GND), U4.6 (A5), U4.7 (A6), U4.8 (A7), U4.9 (A8), U4.10 (GND), U5.3 (GND), U5.8 (GND), U5.13 (GND), U5.18 (GND), U5.23 (GND), U5.28 (GND), U5.33 (AGND), U5.38 (GND), U5.D2 (GND), U6.10 (GND), U7.6 (A4), U7.7 (A5), U7.8 (A6), U7.9 (A7), U7.10 (GND), U8.8 (GND), U9.8 (GND); also elsewhere on the board
unnamed 47: PWR_LED1.2 (A), R3.2; also elsewhere on the board
unnamed: R2.2, U4.15 (B4), U5.15 (GP11)
unnamed: R10.1, R11.2, U2.2
unnamed: R9.1, R12.2, U2.1
unnamed: R8.1, R13.2, U1.13
unnamed: R7.1, R14.2, U1.12
unnamed: R6.1, R15.2, U1.10
unnamed: R16.2, U5.19 (GP14), U7.5 (A3)
unnamed 55: TEST_MODE1.1, U5.16 (GP12); also elsewhere on the board
unnamed: U1.6, U2.4
unnamed: U1.8, U2.9
unnamed: U2.5, U2.8
unnamed: U2.3, U2.10
unnamed: U3.11 (B8), U5.10 (GP7)
unnamed: U3.12 (B7), U5.9 (GP6)
unnamed: U3.13 (B6), U5.7 (GP5)
unnamed: U3.14 (B5), U5.6 (GP4)
unnamed: U3.15 (B4), U5.5 (GP3)
unnamed: U3.16 (B3), U5.4 (GP2)
unnamed: U3.17 (B2), U5.2 (GP1)
unnamed: U3.18 (B1), U5.1 (GP0)
unnamed: U4.16 (B3), U5.14 (GP10)
unnamed: U4.17 (B2), U5.12 (GP9)
unnamed: U4.18 (B1), U5.11 (GP8)
unnamed: U5.20 (GP15), U6.2 (A0)
unnamed: U5.21 (GP16), U6.3 (A1)
unnamed: U5.22 (GP17), U6.4 (A2)
unnamed: U5.24 (GP18), U6.5 (A3)
unnamed: U5.25 (GP19), U6.6 (A4)
unnamed: U5.26 (GP20), U6.7 (A5)
unnamed: U5.27 (GP21), U6.8 (A6)
unnamed: U5.29 (GP22), U6.9 (A7)
unnamed: U5.31 (GP26), U7.2 (A0)
unnamed: U5.32 (GP27), U7.3 (A1)
unnamed: U5.34 (GP28), U7.4 (A2)
unnamed: U5.A (USB_SHIELD), U5.B (USB_SHIELD), U5.C (USB_SHIELD), U5.D (USB_SHIELD)

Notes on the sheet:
WPC
WPC95

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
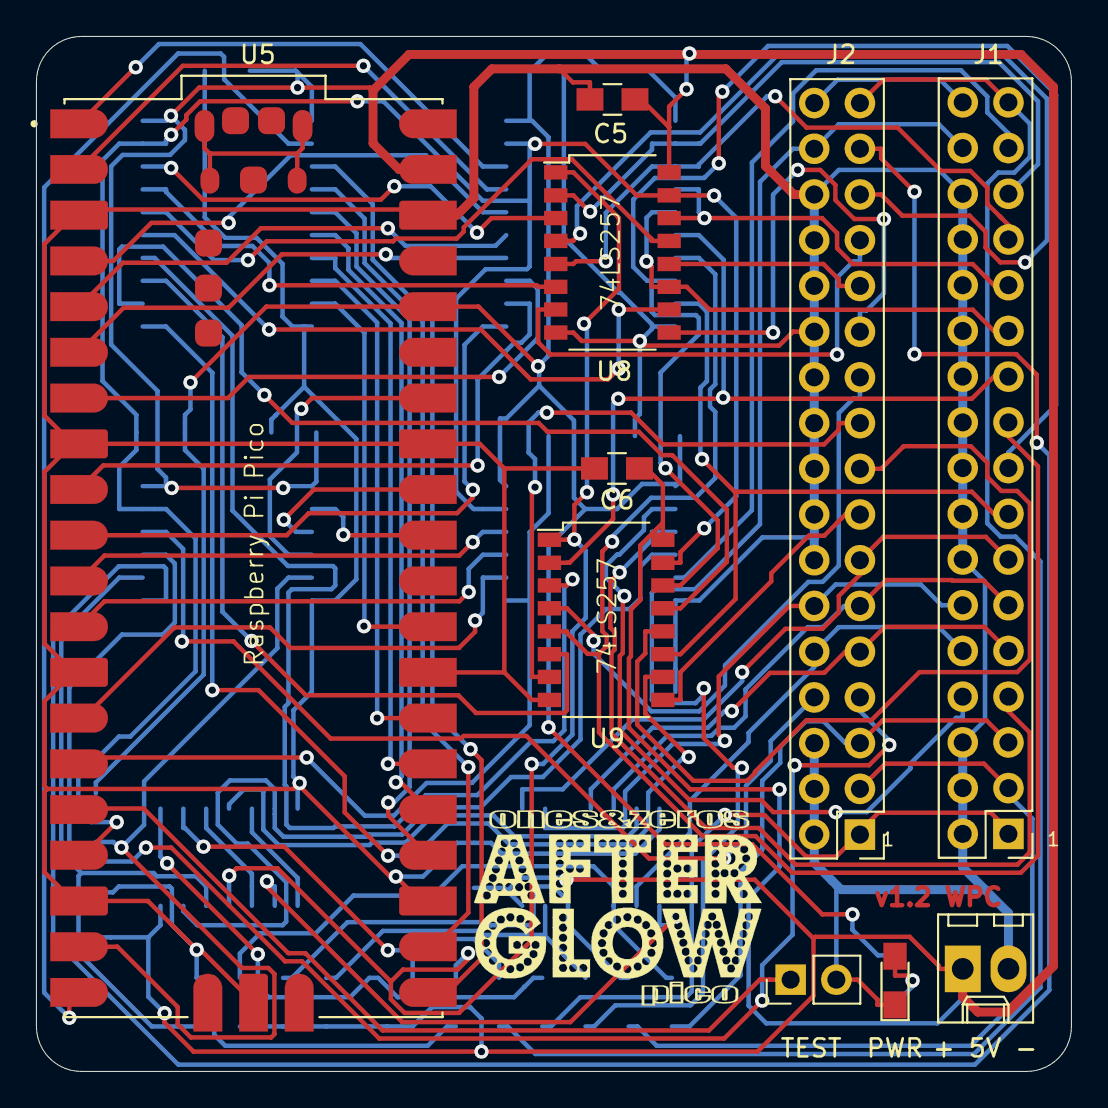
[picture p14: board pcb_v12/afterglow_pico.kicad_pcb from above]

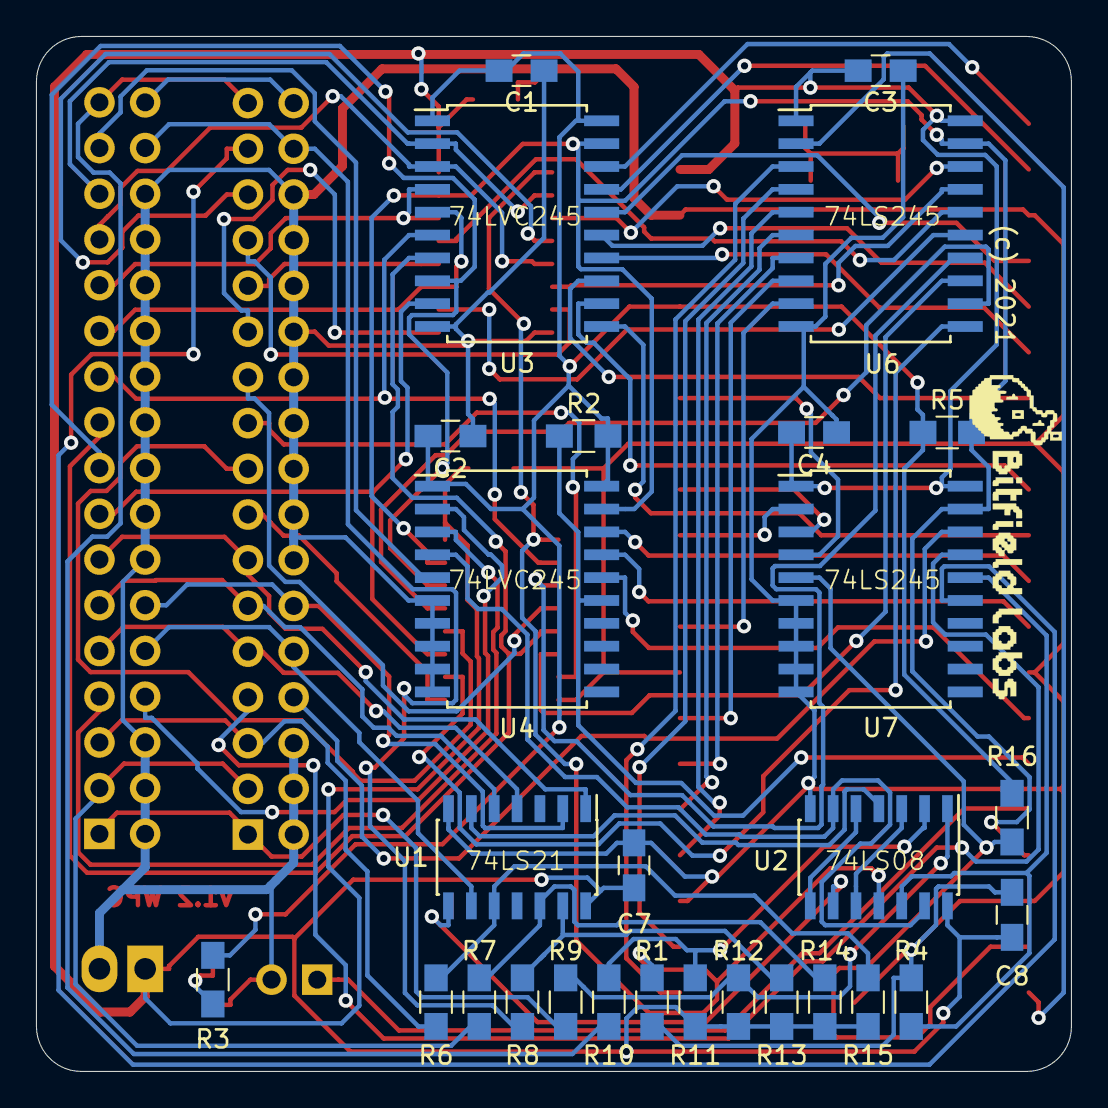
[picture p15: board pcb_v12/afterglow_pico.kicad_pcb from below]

Board: 2 copper layers, 57.5 x 57.5 mm, 40 parts (29 on the bottom side), 84 nets.

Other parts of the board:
+ 5V -: Conn_01x02_Male; Molex_KK-6410-02_02x2.54mm_Straight
AG_LOGO: LOGO; ag_pico_logo_2
BFL_LOGO: LOGO; bl_logo
PWR: LED; LED_0805_HandSoldering
TEST: Conn_01x02; Pin_Header_Straight_1x02_Pitch2.54mm

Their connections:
GND: + 5V -.2, PWR.1, TEST.2; also elsewhere on the board
unnamed 47: PWR.2; also elsewhere on the board
unnamed 55: TEST.1; also elsewhere on the board

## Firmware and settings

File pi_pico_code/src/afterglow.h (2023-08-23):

/***********************************************************************
 *   ___  ___  ___  ___  ___  ___   _    ___  _ _ _ 
 *  | . || __>|_ _|| __>| . \/  _> | |  | . || | | |
 *  |   || _>  | | | _> |   /| <_/\| |_ | | || | | |
 *  |_|_||_|   |_| |___>|_\_\`____/|___|`___'|__/_/ 
 *                                                  pico
 *      Copyright (c) 2021 bitfield labs
 *
 ***********************************************************************
 *  This file is part of the afterglow pinball LED project:
 *  https://github.com/bitfieldlabs/afterglow_pico
 *
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
 *  You should have received a copy of the GNU Lesser General Public
 *  License along with afterglow.
 *  If not, see <http://www.gnu.org/licenses/>.
 ***********************************************************************/

#include <stdio.h> 

//------------------------------------------------------------------------------
// Setup

#define AFTERGLOW_PICO_VERSION 101      // Afterglow pico version number
#define BOARD_REV                13     // Latest supported Afterglow Pico board revision. Currently v1.3
#define SINGLE_UPDATE_CONS        2     // Number of consistent data samples required for matrix update. Helps prevent ghosting.
#define TTAG_INT_A              250     // Matrix update time interval, config A [us]
#define TTAG_INT_B              500     // Matrix update time interval, config B [us]
#define PWM_STEPS_A               8     // Number of brightness steps, config A (only 4, 8 an 16 are currently supported)
#define PWM_STEPS_B               8     // Number of brightness steps, config B (only 4, 8 an 16 are currently supported)
#define PWM_STEPS                 8     // Number of brightness steps (only 4, 8 an 16 are currently supported)
#define ANTIGHOST_DURATION       20     // Duration of anti ghosting [us] (turning off all lamps briefly)
#define DEFAULT_GLOWDUR         140     // Default glow duration [ms]
#define DEFAULT_BRIGHTNESS        7     // Default maximum lamp brightness 0-7
#define DEBUG_SERIAL              1     // Turn debug output via serial on/off
#define PROJECT_BUTTER            1     // Smooth as butter brightness transitions
#define RGB_LED                   1     // Use the RGB LED as status display


// Initialize the afterglow engine
void ag_init();

// Update the afterglow
// This function is called every time interval
void ag_update();

// Afterglow serial communication
// This function must be called frequently in order to process pending
// serial communication events.
void ag_sercomm();

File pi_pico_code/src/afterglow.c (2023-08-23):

/***********************************************************************
 *   ___  ___  ___  ___  ___  ___   _    ___  _ _ _
 *  | . || __>|_ _|| __>| . \/  _> | |  | . || | | |
 *  |   || _>  | | | _> |   /| <_/\| |_ | | || | | |
 *  |_|_||_|   |_| |___>|_\_\`____/|___|`___'|__/_/
 *                                                  pico
 *      Copyright (c) 2021 bitfield labs
 *
 ***********************************************************************
 *  This file is part of the afterglow pinball LED project:
 *  https://github.com/bitfieldlabs/afterglow_pico
 *
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
 *  You should have received a copy of the GNU Lesser General Public
 *  License along with afterglow.
 *  If not, see <http://www.gnu.org/licenses/>.
 ***********************************************************************/

#include <string.h>
#include <math.h>
#include <stdio.h>
#include "afterglow.h"
#include "pico/stdlib.h"
#include "pico/time.h"
#include "pio.h"
#include "pindef.h"

//------------------------------------------------------------------------------
// Some definitions

// Afterglow configuration version
#define AFTERGLOW_CFG_VERSION 3

// original matrix update interval [us]
#define ORIG_INT (2000)

// cycles per original interval, config A
#define ORIG_CYCLES_A (ORIG_INT / TTAG_INT_A)

// cycles per original interval, config B
#define ORIG_CYCLES_B (ORIG_INT / TTAG_INT_B)

// number of columns in the lamp matrix
#define NUM_COL 8

// number of rows in the lamp matrix
#define NUM_ROW 8

// WPC systems strobe the 8 columns
#define NUM_STROBE NUM_COL
#define NUM_NONSTROBE NUM_ROW

// glow duration scaling in the configuration
#define GLOWDUR_CFG_SCALE 10

// test mode setup
#define TEST_MODE_NUMMODES 7                                                       // number of test modes
#define TEST_MODE_DUR 8                                                            // test duration per mode [s]
#define TEST_MODE_DUR_CYCLES_A ((uint32_t)TEST_MODE_DUR * 1000000UL / TTAG_INT_A)  // number of cycles per testmode, config A
#define TEST_MODE_DUR_CYCLES_B ((uint32_t)TEST_MODE_DUR * 1000000UL / TTAG_INT_B)  // number of cycles per testmode, config B
#define TESTMODE_INT (500)                                                         // test mode lamp switch interval [ms]
#define TESTMODE_CYCLES_A ((uint32_t)TESTMODE_INT * 1000UL / (uint32_t)TTAG_INT_A) // number of cycles per testmode interval, config A
#define TESTMODE_CYCLES_B ((uint32_t)TESTMODE_INT * 1000UL / (uint32_t)TTAG_INT_B) // number of cycles per testmode interval, config B

//------------------------------------------------------------------------------
// serial port protocol definition

// write buffer size [bytes]
#define AG_CMD_WRITE_BUF 32

// command terminator character
#define AG_CMD_TERMINATOR ':'

// version poll command string
#define AG_CMD_VERSION_POLL "AGV"

// configuration poll command string
#define AG_CMD_CFG_POLL "AGCP"

// configuration save command string
#define AG_CMD_CFG_SAVE "AGCS"

// configuration reset to default command string
#define AG_CMD_CFG_DEFAULT "AGCD"

// data ready string
#define AG_CMD_CFG_DATA_READY "AGDR"

// acknowledge string
#define AG_CMD_ACK "AGCACK"

// NOT acknowledge string
#define AG_CMD_NACK "AGCNACK"

//------------------------------------------------------------------------------
// Brightness maps

static const uint8_t skMap_256_4_log[256] =
    {
        0, 0, 0, 0, 0, 0, 0, 0, 0, 0, 0, 0, 0, 0, 0, 0, 0, 0, 0, 0, 0, 0, 0, 0, 0, 0, 0, 0, 0, 0, 0, 0,
        0, 0, 0, 0, 0, 0, 0, 0, 0, 0, 0, 0, 0, 0, 0, 0, 0, 0, 0, 0, 0, 0, 0, 0, 0, 0, 0, 0, 0, 0, 0, 0,
        0, 0, 0, 0, 0, 0, 0, 0, 0, 0, 0, 0, 0, 0, 0, 0, 0, 0, 0, 0, 0, 0, 0, 0, 0, 0, 0, 0, 0, 0, 0, 0,
        0, 0, 0, 0, 0, 0, 0, 0, 0, 0, 0, 0, 0, 0, 0, 0, 0, 0, 0, 0, 0, 0, 0, 0, 0, 0, 0, 0, 0, 0, 0, 0,
        0, 0, 0, 0, 0, 0, 0, 0, 0, 0, 0, 0, 0, 0, 0, 0, 0, 0, 0, 0, 0, 0, 0, 0, 0, 0, 1, 1, 1, 1, 1, 1,
        1, 1, 1, 1, 1, 1, 1, 1, 1, 1, 1, 1, 1, 1, 1, 1, 1, 1, 1, 1, 1, 1, 1, 1, 1, 1, 1, 1, 1, 1, 1, 1,
        1, 1, 1, 1, 1, 1, 1, 1, 1, 1, 1, 1, 1, 1, 1, 1, 1, 1, 1, 1, 1, 1, 1, 1, 2, 2, 2, 2, 2, 2, 2, 2,
        2, 2, 2, 2, 2, 2, 2, 2, 2, 2, 2, 2, 2, 2, 2, 2, 2, 2, 2, 2, 2, 2, 2, 2, 2, 2, 2, 2, 2, 2, 2, 3};

static const uint8_t skMap_256_8_log[256] =
    {
        0, 0, 0, 0, 0, 0, 0, 0, 0, 0, 0, 0, 0, 0, 0, 0, 0, 0, 0, 0, 0, 0, 0, 0, 0, 0, 0, 0, 0, 0, 0, 0,
        0, 0, 0, 0, 0, 0, 0, 0, 0, 0, 0, 0, 0, 0, 0, 0, 0, 0, 0, 0, 0, 0, 0, 0, 0, 0, 0, 0, 0, 0, 0, 0,
        0, 0, 0, 0, 0, 0, 0, 0, 0, 0, 0, 0, 0, 0, 0, 0, 0, 0, 0, 0, 0, 0, 0, 0, 0, 0, 0, 0, 1, 1, 1, 1,
        1, 1, 1, 1, 1, 1, 1, 1, 1, 1, 1, 1, 1, 1, 1, 1, 1, 1, 1, 1, 1, 1, 1, 1, 1, 1, 1, 1, 1, 1, 1, 1,
        1, 1, 1, 1, 1, 1, 1, 1, 1, 1, 1, 1, 1, 2, 2, 2, 2, 2, 2, 2, 2, 2, 2, 2, 2, 2, 2, 2, 2, 2, 2, 2,
        2, 2, 2, 2, 2, 2, 2, 2, 2, 2, 2, 2, 2, 2, 2, 2, 3, 3, 3, 3, 3, 3, 3, 3, 3, 3, 3, 3, 3, 3, 3, 3,
        3, 3, 3, 3, 3, 3, 3, 3, 3, 3, 4, 4, 4, 4, 4, 4, 4, 4, 4, 4, 4, 4, 4, 4, 4, 4, 4, 4, 4, 4, 4, 5,
        5, 5, 5, 5, 5, 5, 5, 5, 5, 5, 5, 5, 5, 5, 5, 5, 6, 6, 6, 6, 6, 6, 6, 6, 6, 6, 6, 6, 6, 6, 6, 7};

static const uint8_t skMap_256_16_log[256] =
    {
        0, 0, 0, 0, 0, 0, 0, 0, 0, 0, 0, 0, 0, 0, 0, 0, 0, 0, 0, 0, 0, 0, 0, 0, 0, 0, 0, 0, 0, 0, 0, 0,
        0, 0, 0, 0, 0, 0, 0, 0, 0, 0, 0, 0, 0, 0, 0, 0, 0, 0, 0, 0, 0, 1, 1, 1, 1, 1, 1, 1, 1, 1, 1, 1,
        1, 1, 1, 1, 1, 1, 1, 1, 1, 1, 1, 1, 1, 1, 1, 1, 1, 1, 1, 1, 1, 1, 1, 1, 2, 2, 2, 2, 2, 2, 2, 2,
        2, 2, 2, 2, 2, 2, 2, 2, 2, 2, 2, 2, 2, 2, 2, 2, 2, 2, 2, 3, 3, 3, 3, 3, 3, 3, 3, 3, 3, 3, 3, 3,
        3, 3, 3, 3, 3, 3, 3, 3, 4, 4, 4, 4, 4, 4, 4, 4, 4, 4, 4, 4, 4, 4, 4, 4, 4, 4, 5, 5, 5, 5, 5, 5,
        5, 5, 5, 5, 5, 5, 5, 5, 5, 5, 6, 6, 6, 6, 6, 6, 6, 6, 6, 6, 6, 6, 6, 7, 7, 7, 7, 7, 7, 7, 7, 7,
        7, 7, 7, 8, 8, 8, 8, 8, 8, 8, 8, 8, 8, 8, 9, 9, 9, 9, 9, 9, 9, 9, 9, 9, 10, 10, 10, 10, 10, 10, 10, 10,
        10, 11, 11, 11, 11, 11, 11, 11, 11, 11, 12, 12, 12, 12, 12, 12, 12, 13, 13, 13, 13, 13, 13, 13, 13, 14, 14, 14, 14, 14, 14, 15};

//-------------#include <stdio.h> -----------------------------------------------------------------
// function prototypes
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

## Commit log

2021-12-03 Added schematic pdf
2021-12-03 Added pcb render
2021-12-03 Added v1.1 gerber files
    [afterglow_pico-B_Cu.gbl, afterglow_pico-B_Mask.gbs, afterglow_pico-B_Paste.gbp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]
2021-12-19 PCB v1.2 preparations
    [afterglow_pico.kicad_pcb, afterglow_pico.sch]
2021-12-19 PCB v1.2
    [afterglow_pico.kicad_pcb, afterglow_pico.sch]
2021-12-19 Routing preparations
    [afterglow_pico.kicad_pcb]
2021-12-19 PCB v1.2 routed
    [afterglow_pico-B_Cu.gbl, afterglow_pico-B_Mask.gbs, afterglow_pico-B_Paste.gbp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]
2021-12-20 PCB cosmetix
    [afterglow_pico-B_Cu.gbl, afterglow_pico-B_Mask.gbs, afterglow_pico-B_Paste.gbp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]
2021-12-25 Schematic cosmetics
    [afterglow_pico.sch]
2022-03-11 JLCPCB production files
    [afterglow_pico.kicad_pcb, afterglow_pico.kicad_sch, afterglow_pico.sch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]
2023-01-07 Preparing for PCB v1.3
    [afterglow_pico.kicad_pcb, afterglow_pico.kicad_sch]
2023-01-07 Before routing
    [afterglow_pico.kicad_pcb, afterglow_pico.kicad_sch]
2023-01-08 First PCB v1.3 draft
    [afterglow_pico.kicad_pcb]
2023-01-13 PCB v1.3 progress
    [afterglow_pico.kicad_sch, afterglow_pico_bom_jlc.csv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]
2023-01-27 Routable PCB
    [afterglow_pico.kicad_pcb]
2023-02-25 First attempt
    [afterglow_pico.kicad_pcb, afterglow_pico.kicad_sch]
2023-02-25 Power routing
    [afterglow_pico.kicad_pcb]
2023-02-26 More preparations
    [afterglow_pico.kicad_pcb]
2023-02-26 Even more preparations
    [afterglow_pico.kicad_pcb]
2023-02-26 Forgot a resistor
    [afterglow_pico.kicad_pcb, afterglow_pico.kicad_sch]
2023-02-26 JLCPCB part numbers
    [afterglow_pico.kicad_sch]
2023-02-26 Avoid vias on tracks
    [afterglow_pico.kicad_pcb]
2023-02-26 Minor corrections
    [afterglow_pico.kicad_pcb, afterglow_pico.kicad_sch]
2023-02-26 PCB v1.3
    [afterglow_pico_bom_jlc.csv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]
2023-03-12 PCB v1.3b preparations
    [afterglow_pico.kicad_sch]
2023-03-12 PCB v1.3b
    [afterglow_pico.kicad_pcb, afterglow_pico.kicad_sch, afterglow_pico_bom_jlc.csv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]
2023-03-12 PCB v1.3b touchup
    [afterglow_pico.kicad_sch, afterglow_pico_bom_jlc.csv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]
2023-03-18 Do not populate R17,R18,R20,R21
    [afterglow_pico.kicad_sch, afterglow_pico_bom_jlc.csv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]
2023-03-19 PCB v1.3 picture
2023-08-23 added some comments
    [afterglow_pico.kicad_sch]
2023-09-14 Restored lost PCB v1.3 schematic
    [afterglow_pico.kicad_sch]
2023-10-08 PCB v1.c fixes track cleareance issues
    [afterglow_pico.kicad_pcb, afterglow_pico.kicad_sch]
2023-10-09 PCB v1.3c
    [afterglow_pico.kicad_pcb]

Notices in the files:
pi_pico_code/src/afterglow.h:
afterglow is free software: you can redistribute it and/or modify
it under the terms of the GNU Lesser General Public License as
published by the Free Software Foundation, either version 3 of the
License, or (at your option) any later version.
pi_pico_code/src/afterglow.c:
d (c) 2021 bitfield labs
